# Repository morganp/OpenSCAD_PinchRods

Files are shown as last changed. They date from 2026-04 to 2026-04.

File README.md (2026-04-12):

# OpenSCAD Pinch Rods

A parametric 3D-printable pinch rod tool for checking furniture carcases and boxes for square, and transferring interior dimensions without measuring.

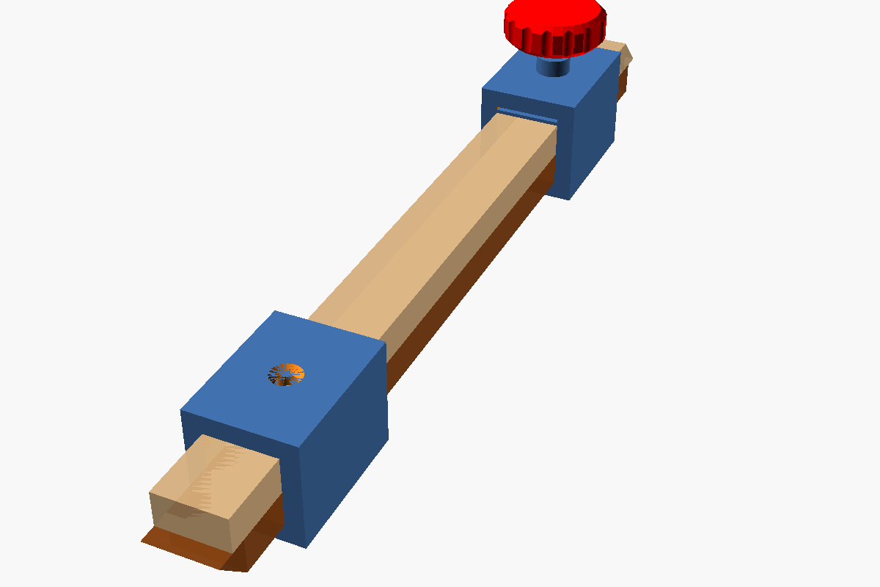
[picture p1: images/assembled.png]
Assembled pinch rods


## What are pinch rods?

Pinch rods are a traditional woodworking measuring tool. Two flat rods overlap and slide through a pair of guides. Place the pointed ends in opposite diagonal corners of a box or cabinet - if both diagonals match, the assembly is square.

They are also used to transfer interior dimensions directly to a workpiece without reading a number off a tape measure.

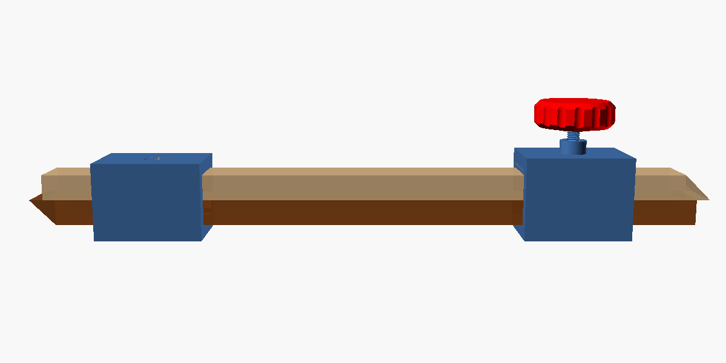
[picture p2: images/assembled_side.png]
Side profile


## How it works

- **Guide 1** (near end) is mounted inverted. Its screw secures it to the top rod.
- **Guide 2** (far end) has a threaded standoff and a clamping membrane. The thumbscrew locks the bottom rod.
- Each guide locks a different rod, so the total span is set in two independent steps.
- Both rods taper to a 45-degree chisel point at opposite ends, seating snugly into corners.

| Guide 1 - inverted, screw on top | Guide 2 - thumbscrew knob |
|---|---|
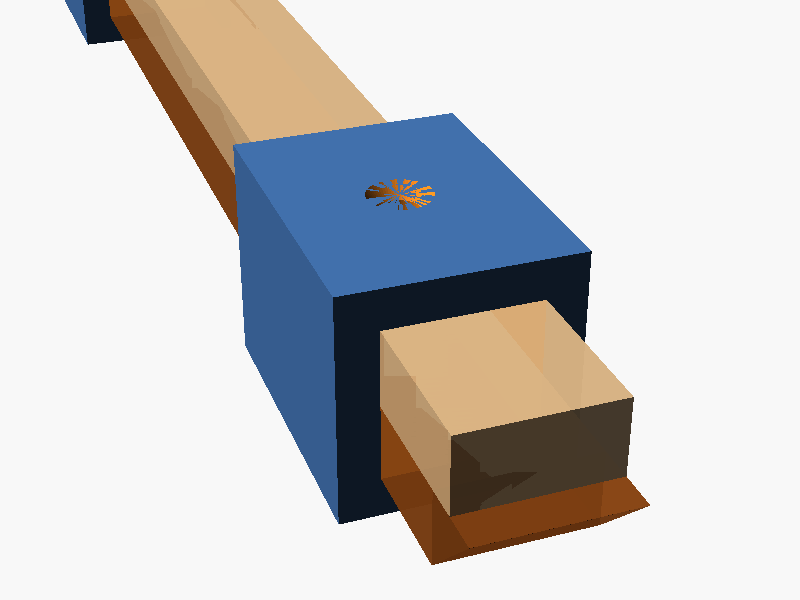
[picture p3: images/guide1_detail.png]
Guide 1 detail
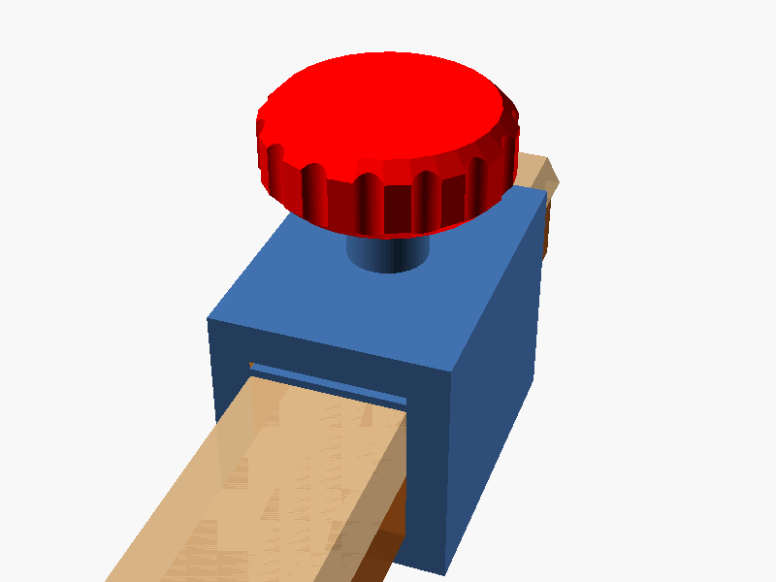
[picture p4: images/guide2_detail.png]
Guide 2 detail
|  |  |

### Tapered tips

Both rods have a 45-degree chisel taper at opposite ends, pointing toward the shared centreline between the two stacked rods so they seat cleanly into square corners.

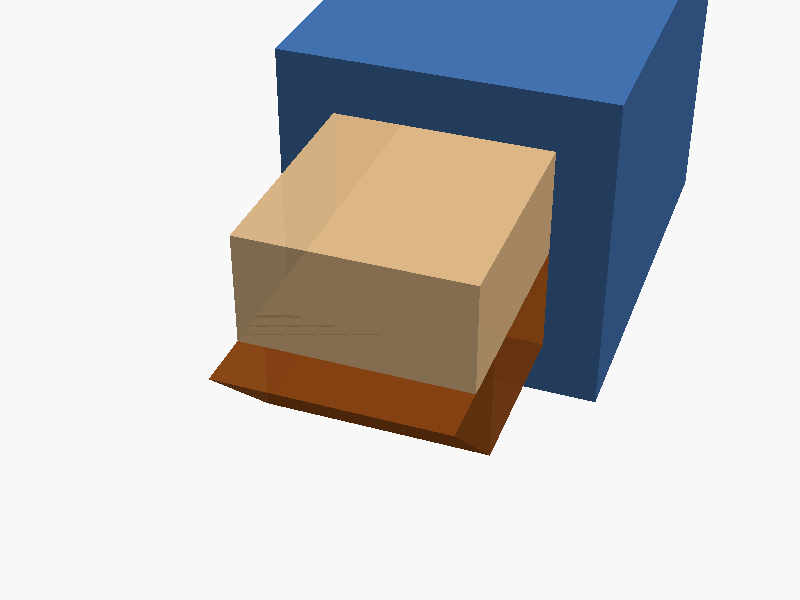
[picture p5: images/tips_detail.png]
Tapered rod tips


## Dependencies

The SCAD file requires two OpenSCAD libraries installed in your libraries folder:

- [BOSL2](https://github.com/BelfrySCAD/BOSL2) - for threaded screws and screw holes
- [parametric-knob-maker](https://github.com/TemptorSent/parametric-knob-maker) - for the thumbscrew knob

## Usage

Open `pinch_rods.scad` in OpenSCAD and set the two variables at the top:

```openscad
// "assembled" - preview the full tool
// "print"     - show a single part for 3mf export
MODE = "assembled";

// Which part to export when MODE = "print":
// "fastener"  "guide1"  "guide2"
PRINT_PART = "guide2";
```

## Printable parts

Three parts are printed separately. Export each as a `.3mf` by setting `MODE = "print"` and selecting the part with `PRINT_PART`.

| Guide 1 | Guide 2 | Thumbscrew knob |
|---|---|---|
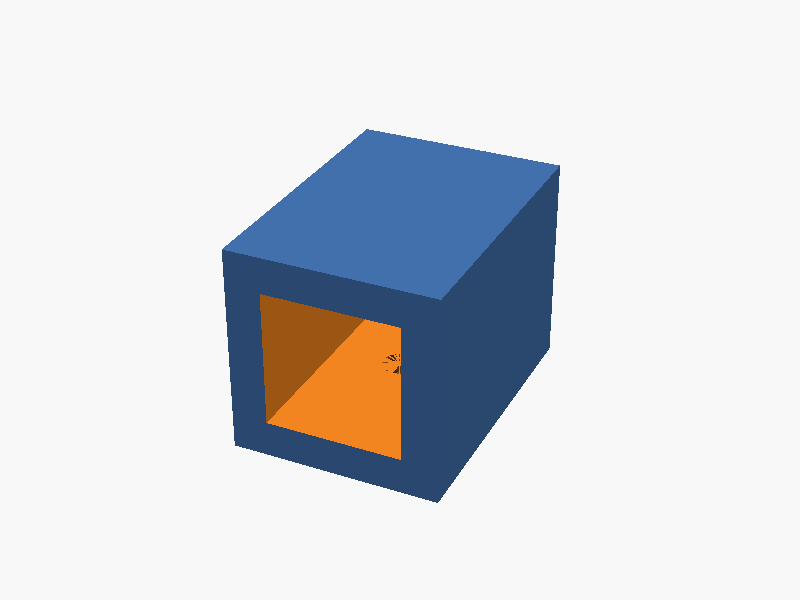
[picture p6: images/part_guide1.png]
Guide 1
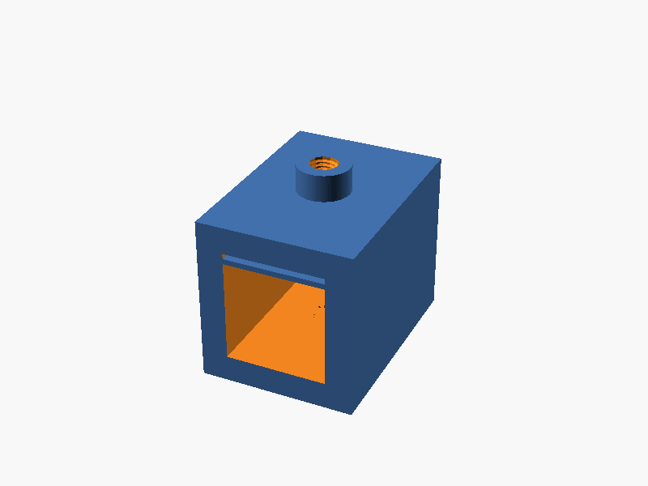
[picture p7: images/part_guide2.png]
Guide 2
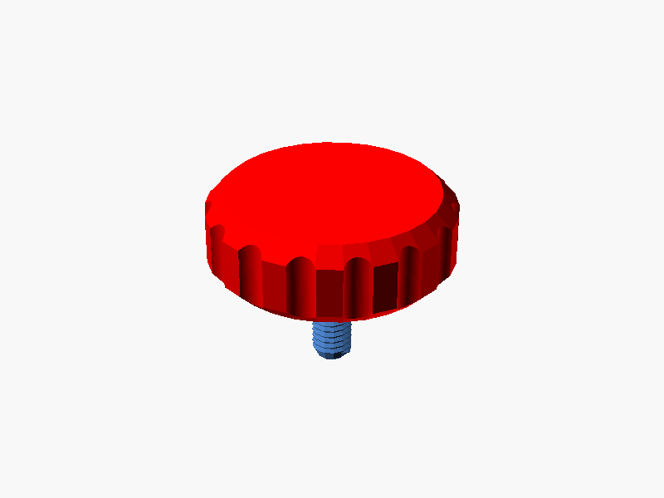
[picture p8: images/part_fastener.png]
Fastener
|  |  |  |

> **Note:** Guide 1 is printed in its natural orientation (flat bottom on the bed) and flipped upside down when assembling.

## Key parameters

| Variable | Default | Description |
|---|---|---|
| `STOCK_THICKNESS` | `9.5 mm` | Height of one rod (two stack to fill the guide opening) |
| `STOCK_WIDTH` | `19 mm` | Width of each rod |
| `WALL_THICKNESS` | `5 mm` | Guide wall thickness |
| `GUIDE_LENGTH` | `40 mm` | Depth of each guide block |
| `ROD_PREVIEW_LENGTH` | `200 mm` | Rod length shown in assembled preview |

## References

- [Make Pinch Rods with Home Center Materials](https://blog.lostartpress.com/2013/04/03/make-pinch-rods-with-home-center-materials/) - Lost Art Press, 2013
- [Crucible Pinch Rods Available](https://blog.lostartpress.com/2020/03/16/crucible-pinch-rods-available/) - Lost Art Press, 2020
- [New Pinch Rods in Development](https://blog.lostartpress.com/2025/02/06/new-pinch-rods-in-development/) - Lost Art Press, 2025
- [Design reference notes](pinch_rods_reference.md)

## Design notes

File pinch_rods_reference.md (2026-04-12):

# Pinch Rods - Design Reference

## What Are Pinch Rods?

Pinch rods are a woodworking measuring tool used to check whether a box, cabinet, or carcase is square. They consist of two thin rods with pointed ends that overlap and slide past each other. The user nestles the pointed ends into opposite diagonal corners of an assembly, locks the rods in place, then checks that the same length fits the other diagonal. Equal diagonals = square assembly.

They are also used to transfer interior dimensions directly to a workpiece without reading a number off a tape measure.

## How They Work

```
  corner A ◄────────────────────────── rod 1 tip
                        ┌──────┐
            ════════════╪══════╪════════════
            ════════════╪══════╪════════════
                        │clamp │
            ════════════╪══════╪════════════
            ════════════╪══════╪════════════
                        └──────┘
  rod 2 tip ──────────────────────────► corner B
```

1. Extend rods to span one diagonal corner to corner
2. Lock the thumbscrew at the crossing/guide point
3. Rotate 90 degrees and check the other diagonal - it should fit snugly
4. Adjust the box if needed (clamp across the longer diagonal), recheck

## Design Variants

### Traditional / Home-Center (2013 Lost Art Press)
- Two thin wood sticks: ~5/16" x 5/8" x 30" (8mm x 16mm x 760mm)
- Cross-section slides through a steel square tube sleeve (3/4" tube, 7/8" long)
- One sleeve per rod; thumbscrew is 1/4-20 tapped into the steel tube
- Pointed ends whittled or sanded to fit into corners
- Very low cost (~$12/set in hardware)

### Crucible Tool (brass hardware, 2020)
- Wood rods supplied by user, brass hardware clamps onto them
- Two square brass blocks - one has a knurled thumbscrew on top, one is fixed
- Thumbscrew has a concentrated point tip that digs slightly into the wood to lock positively (won't slip even if dropped)
- Blocks slide along the rods; lock one block, slide other rod to fit
- Based on an antique design from Roy Underhill's shop
- Hardware sells for ~$48; wood replaced by user if ever worn out

### All-Metal Prototype (2025, Machine Time / Craig Jackson)
- Both rods are 1/4" keystock (square metal bar stock)
- Standard kit: two 12" rods; users can buy 36" keystock separately for larger work
- Beveled ends at approximately 60 degrees to seat snugly in corners
- Central clamp/slider mechanism locks the two rods relative to each other
- Moving away from brass to reduce cost; all-metal construction
- Expected release: Summer 2025

## Key Geometry Principles

- **Rods overlap** in the middle - they do not butt end-to-end
- **The guide/clamp straddles both rods** where they cross, allowing one or both to slide
- **One rod locks**, the other slides to set total length, then the sliding rod locks too
- **Pointed or beveled ends** are essential - they self-locate in square corners
- **Flat/rectangular cross-section** rods are traditional (resist twist better than round)
- Length range: typically 12"-36" working range depending on overlap amount

## Use Cases

1. Checking carcases and boxes for square during glue-up (primary use)
2. Squaring an out-of-square assembly by clamping across the longer diagonal
3. Transferring interior measurements directly (set to fit, carry to workpiece, mark)

## Notes for 3D Printed Design

- The guide blocks must allow both rods to pass through with minimal slop
- One guide locks with a thumbscrew (M5 works well); the second guide can be fixed or also lockable
- The thumbscrew should press against the rod face grain, not the edge, for best grip
- A small standoff or boss to house the threaded insert improves thread engagement
- Chamfered screw holes in the guide base allow screwing the guide to the stock if desired
- Print in orientation that puts layer lines along the length of the guide for strength
- Rod cross-section in current SCAD: 19mm wide x 9.5mm tall per rod (approx 3/4" x 3/8")
- Two rods stack vertically inside the guide, so the guide opening is 19mm x 19mm total
- `STOCK_THICKNESS = 19/2` in the code reflects this - it is the thickness of one rod, not both

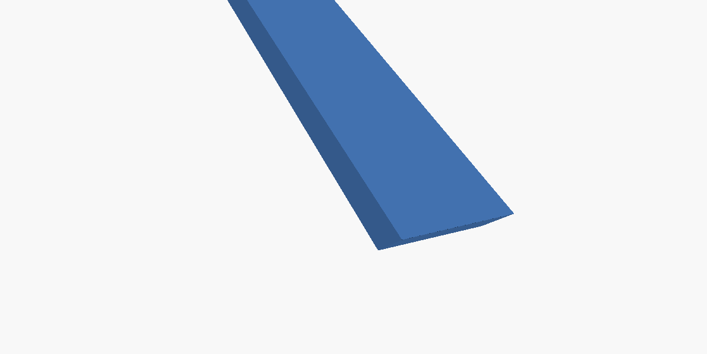
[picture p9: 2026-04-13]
images/part_rod.png

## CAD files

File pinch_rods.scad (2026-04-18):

// https://en.wikibooks.org/wiki/OpenSCAD_User_Manual/Libraries
// /Users/morgan/Documents/OpenSCAD/libraries
include <parametric-knob-maker/parametric_knob.scad>
include <BOSL2/std.scad>
include <BOSL2/threading.scad>
include <BOSL2/screws.scad>


// ── Display mode ──────────────────────────────────────────────────────────────
//   "assembled" : both guides + two rod sticks shown in working position
//   "print"     : single part laid flat for 3mf export (select with PRINT_PART)
MODE = "print";

// Which part to show when MODE = "print"
//   "fastener"  "guide1"  "guide2"  "rod"
PRINT_PART = "guide2";


// ── Stock / wall dimensions ───────────────────────────────────────────────────
STOCK_THICKNESS = 19/2;  // height of ONE rod - two stack to fill the opening
STOCK_WIDTH     = 19;    // width of each rod

// ── Rod print tolerances ──────────────────────────────────────────────────────
ROD_TOL_SIDE = 0.15;  // removed from each side of width (total 0.2 mm narrower)
ROD_TOL_TOP  = 0.15;  // removed from top face only (2 rods = 0.2 mm total height)

rod_width     = STOCK_WIDTH     - 2 * ROD_TOL_SIDE;
rod_thickness = STOCK_THICKNESS - ROD_TOL_TOP;

WALL_THICKNESS  = 5;
CHAMFER         = 1.0;  // edge chamfer on all guide outer faces (mm)

GUIDE_LENGTH    = 40;

// Calculated outside dimensions
guide_width  = STOCK_WIDTH      + 2*WALL_THICKNESS;
guide_height = STOCK_THICKNESS*2 + 2*WALL_THICKNESS;

guide_opening_width  = STOCK_WIDTH;
guide_opening_height = STOCK_THICKNESS * 2;

stand_off_height = 5;
KNOB_THREAD_LEN  = 12;

// Length of each rod stick shown in assembled preview
ROD_PREVIEW_LENGTH = 200;

// Length of the printable rod (adjust to suit your workpiece range)
ROD_PRINT_LENGTH = 160;


// ── Top-level dispatcher ──────────────────────────────────────────────────────
if (MODE == "assembled") {
    assembled();
} else {
    if      (PRINT_PART == "fastener") fastener();
    else if (PRINT_PART == "guide1")  guide1();
    else if (PRINT_PART == "guide2")  guide2();
    else if (PRINT_PART == "rod")     rod();
}


// ── Assembled preview ─────────────────────────────────────────────────────────
// Both guides are centred on the Y axis of the guide() primitive, so we shift
// each by +GUIDE_LENGTH/2 so guide1 sits at Y 0..GUIDE_LENGTH and guide2 sits
// at the far end of the rod span.
//
// Rod tips are on opposite ends of the assembled tool, both bevelled toward the
// shared centreline (Z = guide_height/2 = 14.5 mm):
//   bottom rod - taper at NEAR end, tip points UP   to centreline
//   top    rod - taper at FAR  end, tip points DOWN to centreline

module assembled() {
    // Z extents of the two stacked rods inside the guide opening
    rod_lo_z = guide_height/2 - STOCK_THICKNESS;  // 5 mm   - floor of bottom rod
    rod_hi_z = guide_height/2;                     // 14.5 mm - centreline

    guide_span = ROD_PREVIEW_LENGTH - GUIDE_LENGTH;

    // Guide 1 near end - inverted so its screw hole is at the TOP and secures the TOP rod.
    // Rotate 180 around X (flips Z and Y), then translate back up by guide_height so the
    // opening stays at Z 5..24 (symmetric around guide_height/2) and the rods still pass through.
    translate([0, GUIDE_LENGTH/2, guide_height])
        rotate([180, 0, 0])
            guide1_body();

    // Guide 2 far end
    g2_y = GUIDE_LENGTH/2 + guide_span;
    translate([0, g2_y, 0])
        guide2_body();

    // Fastener seated in guide2 standoff, thread pointing down into the hole.
    // anchor=BOTTOM so Z=0 is the screw tip; knob sits KNOB_THREAD_LEN above.
    // Standoff top = guide_height+2+stand_off_height = 36 mm.
    // Tip at Z=28 gives 8 mm of thread engagement; knob clears standoff by 4 mm.
    translate([0, g2_y, (guide_height + 2 + stand_off_height) - KNOB_THREAD_LEN + 4])
        fastener();

    // Bottom rod: tip at near end, taper points up to centreline
    // Starts 25 mm before guide1's near face (Y=0) so it is visible on both sides.
    color("SaddleBrown", 0.85)
    translate([0, -25, rod_lo_z])
        rod_stick(ROD_PREVIEW_LENGTH + 50, taper_at_start=true);

    // Top rod: tip at far end, taper points down to centreline
    // Starts 20 mm before guide1's near face so it is also visible on both sides.
    color("BurlyWood", 0.85)
    translate([0, -20, rod_hi_z])
        rod_stick(ROD_PREVIEW_LENGTH + 50, taper_at_start=false);
}

// Single pinch rod stick with a 45-degree chisel taper at one end.
// Rod runs Y=0 to Y=length, centred on X=0, Z=0 to Z=STOCK_THICKNESS.
//   taper_at_start=true  : tip at Y=0,      knife-edge at Z=STOCK_THICKNESS (up)
//   taper_at_start=false : tip at Y=length,  knife-edge at Z=0              (down)
// 45 degrees => taper run = STOCK_THICKNESS.
module rod_stick(length, taper_at_start=true) {
    taper_len = rod_thickness; // run = rise for 45 deg

    // Straight section
    translate([-rod_width/2, taper_at_start ? taper_len : 0, 0])
        cube([rod_width, length - taper_len, rod_thickness]);

    // Tapered section - convex hull of tip line and full cross-section slab
    if (taper_at_start) {
        // Tip at Y=0, knife-edge at top face - points up toward centreline
        hull() {
            translate([-rod_width/2, 0,          rod_thickness - 0.01])
                cube([rod_width, 0.01, 0.01]);
            translate([-rod_width/2, taper_len,  0])
                cube([rod_width, 0.01, rod_thickness]);
        }
    } else {
        // Tip at Y=length, knife-edge at bottom face - points down toward centreline
        hull() {
            translate([-rod_width/2, length - 0.01,      0])
                cube([rod_width, 0.01, 0.01]);
            translate([-rod_width/2, length - taper_len, 0])
                cube([rod_width, 0.01, rod_thickness]);
        }
    }
}


// ── Bare guide bodies (no placement translate, used by both modes) ─────────────

module guide1_body() {
    difference() {
        guide(guide_width,        GUIDE_LENGTH,   guide_height,
              guide_opening_width, GUIDE_LENGTH+2, guide_opening_height);
        // countersunk screw hole through bottom wall
        cylinder(h=WALL_THICKNESS, d=5, center=false, $fn=64);
        cylinder(h=2, d1=8, d2=5, center=false, $fn=64);
    }
}

module guide2_body() {
    guide_height_p2         = guide_height + 2;
    guide_opening_height_p2 = guide_opening_height + 2;
    difference() {
        union() {
            guide(guide_width,        GUIDE_LENGTH,   guide_height_p2,
                  guide_opening_width, GUIDE_LENGTH+2, guide_opening_height_p2);

            // Standoff boss for thumbscrew threads
            translate([0, 0, guide_height_p2])
                cyl(h=stand_off_height, d=10, anchor=BOTTOM, chamfer2=CHAMFER);

            // Clamping membrane - corner-chamfered to match guide body outline
            translate([0, 0, guide_height_p2 - WALL_THICKNESS - 1 - 0.5])
                linear_extrude(height=1, center=true)
                    rect([guide_width, GUIDE_LENGTH], chamfer=CHAMFER);
        }
        // Threaded M5 hole down through the standoff
        translate([0, 0, guide_height_p2 + stand_off_height])
            screw_hole("M5", thread=true, l=stand_off_height+WALL_THICKNESS, anchor=TOP);
        // Countersunk screw hole through bottom wall
        cylinder(h=WALL_THICKNESS, d=5, center=false, $fn=64);
        cylinder(h=2, d1=8, d2=5, center=false, $fn=64);
    }
}


// ── Individual part modules (print mode) ──────────────────────────────────────

// Slider knob / fastener
module fastener() {
    union() {
        screw(spec="M5", length=KNOB_THREAD_LEN+1, thread=true, anchor=BOTTOM);
        translate([0, 0, KNOB_THREAD_LEN])
            knob(10, offset_height=1);
    }
}

// Guide 1 - offset for print layout
module guide1() {
    translate([0, -(GUIDE_LENGTH*2), 0])
        guide1_body();
}

// Guide 2 - offset for print layout
module guide2() {
    translate([0, GUIDE_LENGTH*2, 0])
        guide2_body();
}

// Printable rod - flat on the build plate (Z=0 to Z=STOCK_THICKNESS).
// Both rods are the same shape; print two and flip one when assembling.
// The 45-degree taper is at Y=0 with the knife-edge at the top face,
// which is the most printable orientation (no overhangs on the taper).
// Adjust ROD_PRINT_LENGTH to suit your workpiece range.
module rod() {
    rod_stick(ROD_PRINT_LENGTH, taper_at_start=true);
}
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

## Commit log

2026-04-12 Initial commit: OpenSCAD pinch rods design
    Parametric pinch rod guides and fastener using BOSL2 library.
    Includes guide1, guide2, and threaded knob/fastener modules.
    [pinch_rods.scad]
2026-04-12 Add pinch rods design reference document
    Scraped and synthesised from three Lost Art Press articles (2013, 2020, 2025).
    Covers tool purpose, three design variants, key geometry principles, and notes
    specific to the 3D printed version.
2026-04-12 Add assembled preview mode and refactor part switching
    Introduces MODE variable: "assembled" shows both guides + two coloured rod
    sticks in working position; "print" shows the part selected by PRINT_PART
    ready for 3mf export. Extracts guide1_body() and guide2_body() so geometry
    is shared between both modes without duplication.
    [pinch_rods.scad]
2026-04-12 Add 45-degree chisel tapers to assembled rod preview
    Each rod now has a tapered end pointing toward the shared centreline (Z=14.5mm):
    bottom rod taper at near end pointing up, top rod taper at far end pointing down.
    Taper is generated via hull() of a tip-line and a full cross-section slab.
    Adds rod_stick(length, taper_at_start) module used by assembled().
    [pinch_rods.scad]
2026-04-12 Invert guide1 in assembled view so each guide secures a different rod
    guide1 is rotated 180 deg around X then shifted back up by guide_height.
    The opening remains at Z 5..24 (symmetric around the centreline) so both
    rods still pass through. The screw hole moves from the bottom (Z=0) to the
    top (Z=guide_height), placing it adjacent to the top rod.
    guide2 membrane clamps the bottom rod; guide1 screw secures the top rod.
    Print-mode guide1() is unchanged - print flat, flip when assembling.
    [pinch_rods.scad]
2026-04-12 Move top rod start before guide1 so rods are visible on all sides
    Top rod was starting at Y=15 (inside guide1 Y=0..40), hiding it on the near
    face. Moved to Y=-20 and extended length to match, so both rods now protrude
    past both faces of guide1.
    [pinch_rods.scad]
2026-04-12 Add fastener to assembled view seated in guide2 standoff
    Fastener placed with screw tip 8 mm into the standoff hole and knob 4 mm
    above the standoff top. anchor=BOTTOM on the screw means no flip required;
    tip at Z=28 with knob at Z=40 (standoff top is Z=36).
    [pinch_rods.scad]
2026-04-12 Add README with rendered images
    Seven OpenSCAD CLI renders: assembled hero, side profile, guide1/guide2
    close-ups, tapered tips, and all three printable parts. README covers
    usage, parameters, dependencies, and references.
2026-04-12 Fix typo: rename fastner to fastener throughout
    Module, PRINT_PART string, image filename, and README all updated.
    [pinch_rods.scad]
2026-04-13 Add printable rod part with 45-degree chisel taper
    Adds ROD_PRINT_LENGTH variable (default 300 mm) and rod() module for
    print mode. Both rods are the same shape - print two, flip one on
    assembly. Taper at Y=0 with knife-edge at top face for clean printing
    with no overhangs. Removes completed taper TODO.
    [pinch_rods.scad]
2026-04-13 Add export_parts.sh to batch export all parts as 3mf
    Loops over guide1, guide2, fastener, rod and calls openscad CLI with
    MODE="print" and the appropriate PRINT_PART override. Output goes to
    ./export/ (gitignored). Usage: ./export_parts.sh [output_dir]
2026-04-18 Add rod tolerances, chamfers, and slot lead-in geometry
    - Rod width reduced by 0.15mm per side, thickness by 0.15mm on top face
    for clearance fit inside guide opening
    - All guide outer edges chamfered (CHAMFER = 1.0mm)
    - Standoff boss top edge chamfered, underside left square
    - Guide slot entries get hull-based lead-in chamfers at both Y-end faces
    - Clamping membrane corners chamfered via rect() to match guide footprint
    [pinch_rods.scad]
